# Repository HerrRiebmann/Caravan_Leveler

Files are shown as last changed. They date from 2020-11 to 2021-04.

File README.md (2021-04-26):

# Caravan Leveler
ESP32 digital water level bubble with an ADXL345 Accelerometer

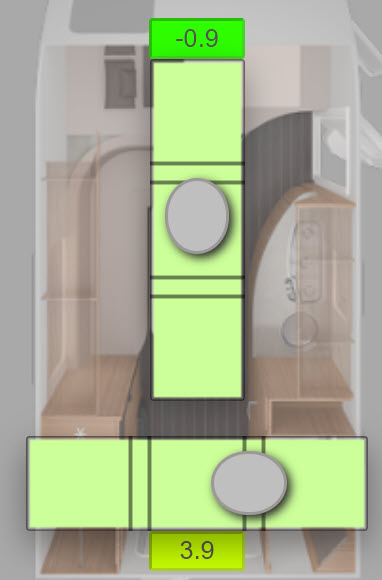
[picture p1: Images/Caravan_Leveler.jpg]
Caravan Leveler


An ESP WROOM32 will create a hotspot with a captive portal.
This captive portal will force the phone to open up a login-site (_which represents the water level_).

## Contents
* [Usage](#usage)
* [Video](#video)
* [3D Case](#3D-Case)
* [Things](#Things)
* [HardwareComponents](#HardwareComponents)
  * [Wiring](#Wiring)
  * [SPIFFS Upload](#SPIFFS-Upload)
  * [Libraries](#Libraries)
  * [OTA (Over the Air Update)](#OTA-Over-the-Air-Update)
  * [Power switch](#Power-Switch)
* [Compatibility](#Compatibility)
* [Disclaimer](#Disclaimer)

### Intention
The intention was, to attach this to my caravan (_Knaus Sport & Fun_) and provide it with 12V on-board voltage.
When arriving at a campingside, the phone will automatically connect to this as a known hotspot, open up the digital leveler and I can happily crank the supports.

In short: Lazy me doesn´t want to constantly walk to the inside and check the level &#129335;

## Usage

Captive Portal (_Android 10_):

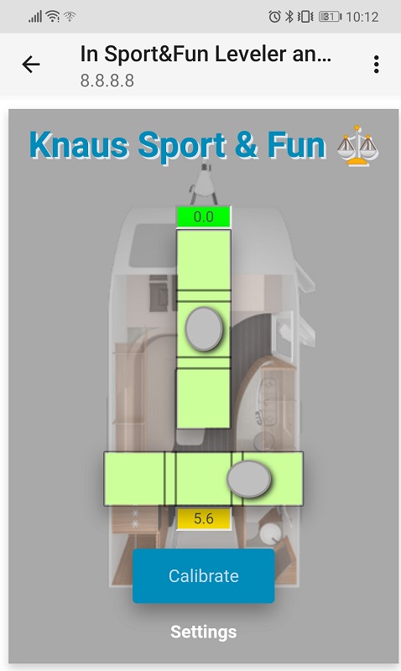
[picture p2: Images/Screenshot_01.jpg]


**Calibrate** sets the values to zero

Settings:

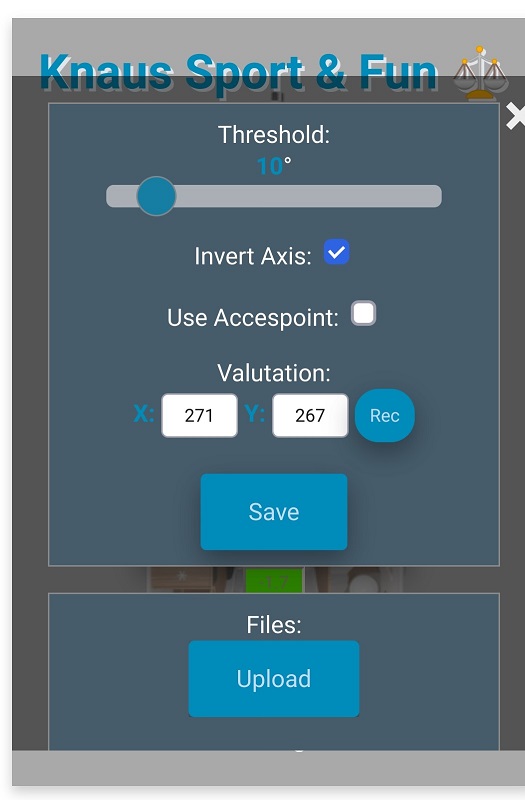
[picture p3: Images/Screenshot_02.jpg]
Settings


**Threshold** describes the water bubble maximum value, when it will reach the scales end

**Invert Axis** swaps X- and Y-Axis

**Use Accesspoint** or connect to an existing WiFi (_SSID and Pasword required in code_)

**Valutation** represents the values range from 0° to 90° (_or -90° to 0°_)

**Rec** starts recording the minimum and maximum values on both axis. Tip the board over to 90 degrees on every side. Afterwards, hit **End** to see those values.

**Save** will store all values above, to the ESP32

**Upload** loads a file to the SPIFFS. To overwrite existing files, the filename must be equal (see [/data](https://github.com/HerrRiebmann/Caravan_Leveler/tree/main/data))!

## Video
(http://www.youtube.com/watch?v=iUhjaghWvkY "Caravan Leveler")

## 3D Case
3D Printed case with wood filament:

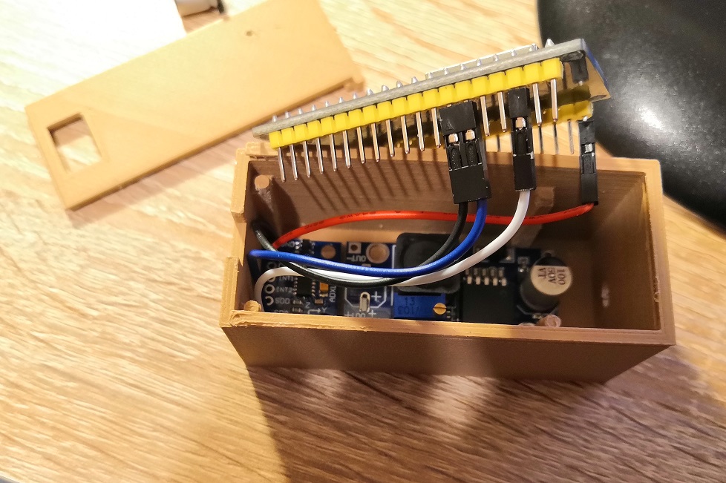
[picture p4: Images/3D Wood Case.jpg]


**Attention!** The wood filament comes thicker, so you might have to sand parts of the case. That´s not necesary using regular PLA.

Hotspot (_Android 4.4.3_):

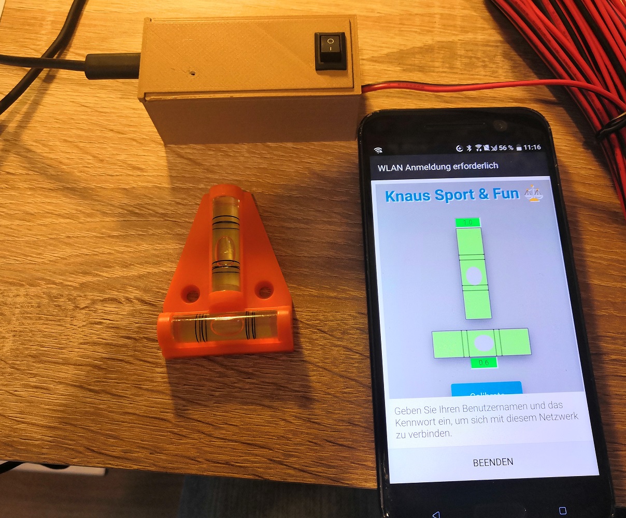
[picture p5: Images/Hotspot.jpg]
Hotspot


## Things
### HardwareComponents
* ESP WROOM32
* ADXL345 (_Accelerometer / Gyro_)
* LM2596 (_DC-DC converter_)
* Rocker switch (_15mm x 10mm_)
* 3D Printed Case

### Wiring
ESP 32 | ADXL345
------- | --------
G22 | SCL
G21 | SDA
3.3V | VCC
GND | GND

ESP 32 | LM2596
------- | --------
5V | OUT+
GND | OUT-

### SPIFFS Upload
To upload the HTML, JS and CSS files, I´ve used the [Arduino ESP32 filesystem uploader](https://github.com/me-no-dev/arduino-esp32fs-plugin)
You can find the latest release [here](https://github.com/me-no-dev/arduino-esp32fs-plugin/releases/) and a tutorial on [RandomNerdTutorials](https://randomnerdtutorials.com/install-esp32-filesystem-uploader-arduino-ide/)

### Libraries
* Adafruit Unified Sensor (1.0.3)
* Adafruit ADXL345 (1.2.2)

### OTA (Over the Air Update)
You should see the ESP32 in Arduino IDE under Tools -> Port -> Network-Interfaces (Sport&Fun Leveler at _IP-Adress_)
For more information see [RandomNerdTutorials](https://randomnerdtutorials.com/esp32-over-the-air-ota-programming/)

### Power Switch
The DC converter is connected to the 12V net. So it will only be powered, enabling the boardnet (_as you can see at the start of the video_).
To prevent the converter being powered all the time, standing on a campingside, I´ve added a illuminated momentary switch:
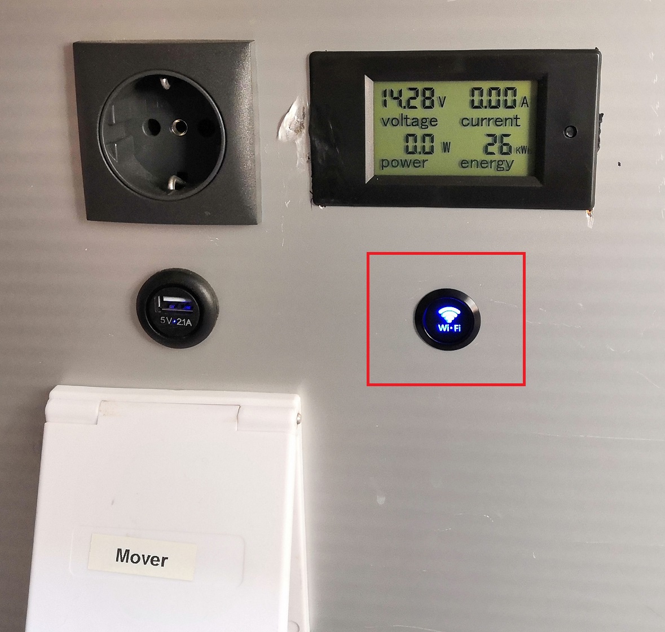
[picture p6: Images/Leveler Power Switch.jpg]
Power Switch

19mm momentary blue led switch. Color and various logos can be ordered on well known, chinese express online shop ;) 

Got a relais in between, which disconnects after about 15 minutes, after powering up.
Not easy to find the right one, which immediately closes the relais and opens it after a specific period of time.
Then remain like that, until the powersupply is cut off. A **JK 11** timing relais (V2.0.2021-1) worked great, using a jumper instead of a trigger button.
But not yet constantly installed...

## Compatibility
Tested on iOS and Android 4.4.3, 8 and 10.

(*And all estabished none-mobile Browsers, like Firefox, Edge or Chrome*)

### Disclamer
The ADXL345 is **not** a proper device to show exact degrees! It´s an accelerometer, which goal was to measure movements by gravitation.
So all results are just approximation.

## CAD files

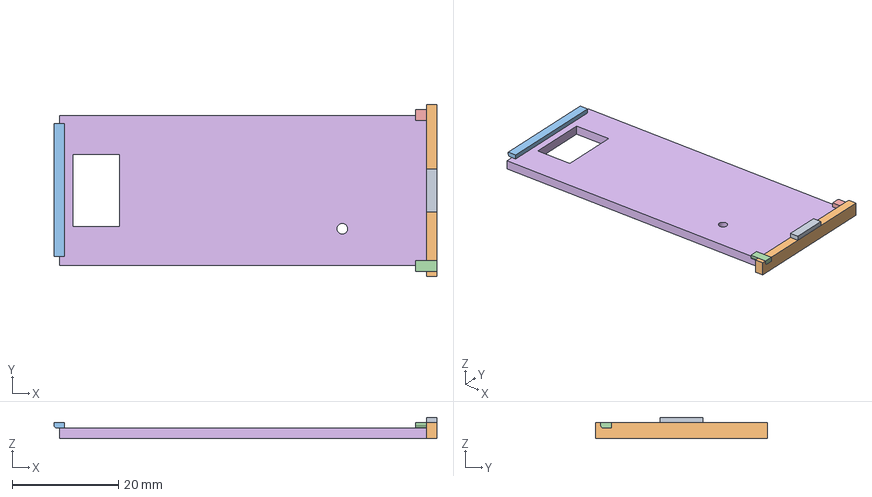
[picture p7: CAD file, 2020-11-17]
3D Case/Camping Leveler - Lid.FCStd
72.0 x 32.4 x 4.00 mm
USB Cut
BaseEnd

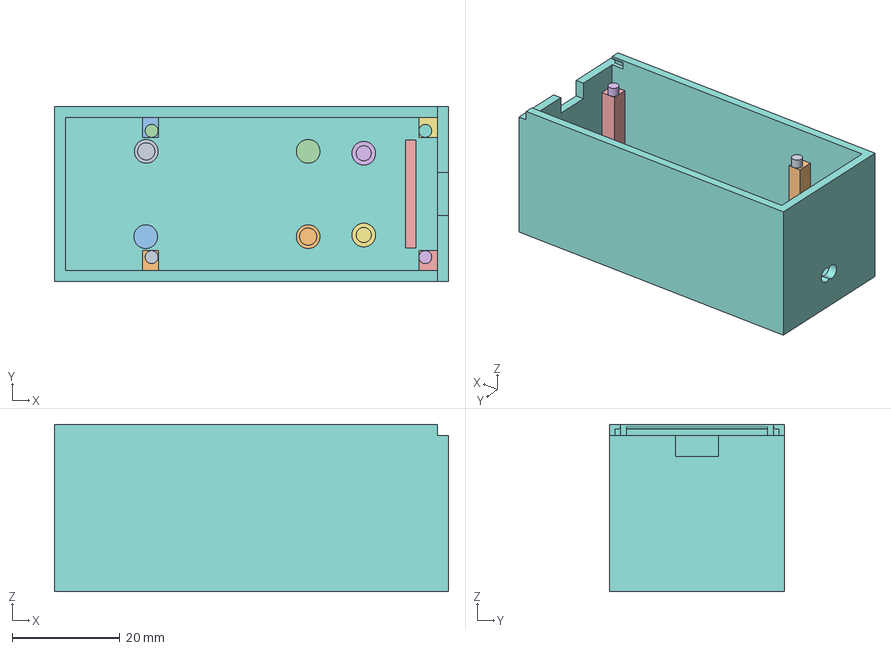
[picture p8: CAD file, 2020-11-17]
3D Case/Camping Leveler - Box.FCStd
73.0 x 32.4 x 31.0 mm
Pin1
Pin2
BaseZylinder002
BaseZylinder003
Stand1
Stand2
Stand3
Stand4
Würfel
Pin3
Pin4

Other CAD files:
3D Case/CampingLevelerBox.stl
3D Case/CampingLevelerLid.stl

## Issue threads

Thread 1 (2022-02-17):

Befestigung der Leiterplatten im Gehäuse

xsnoopy1958, 2022-02-17:
Hallo,
ich bin dabei das Projekt nachzubauen.
3D-Gehäuse ist auch schon gedruckt.
Wie befestigt man nun am besten die Leiterplatten in dem Gehäuse?

Danke für Hilfe und Rückmeldung

HerrRiebmann, 2022-02-17:
Hi,
freut mich, dass Du die digitale Wasserwaage nachbaust :)
Im Gehäuse sind unten kleine "Pinne", wo der Gyro eingeklipst werden kann (auf der Seite des USB-Ausschnittes.
Auf der anderen Seite kommt dann das Netzteil hin.
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
Zu guter Letzt sind noch 4 Stege nach oben rausgeführt, wo dann der ESP sitzen soll.

Sehe aber gerade, dass mein ESP wohl die Ausführung mit mehr Pins ist. Der ist nämlich länger als die anderen, die ich hier liegen habe:
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
Wenn Du mir die Ausmaße gibst, kann ich die sicherlich kurz umkonstruieren!

xsnoopy1958, 2022-02-17:
Hallo ,
danke für die schnelle Antwort.
ja, die Pins habe ich schon gefunden, mache mir nur etwas Sorgen, dass die Leiterplatten sich auf dauer lösen können.
Kann man eine zusätzliche Sicherung anbringen, damit sie wirklich dauerhaft fest sitzen?
Könnte evtl. ein kleiner Tropfen Heißklebstoff nützlich sein?
Gibt es eine Möglichkeit das Bild mit dem Knaus Wohnwagen auf ein anderes Wohnwagenmodell zu ändern?
Noch ne Frage: ist die Level-Anzeige genau genug?
Gruß
Bernd

xsnoopy1958, 2022-02-17:
Habe noch etwas vergessen,
der Deckel ist sehr locker im Gehäuse.
Wie kann ich den gut und fest fixieren?

HerrRiebmann, 2022-02-17:
Hi Bernd,
bei mir sitzt die Platine wirklich spack auf diesen Pins. Da bewegt sich nichts, auch während zahlreichen Fahrten ist alles noch an Ort und Stelle.
Ein Tröpfchen Heißkleber schadet sicherlich nicht. Sei aber bitte vorsichtig, denn zu meiner Überraschung leitet der Kleber.
Hat in einem Projekt mit Touch-Bedienung zu zahlreichen grauen Haaren geführt.

Der Deckel ist leider recht stümperhaft mit meinen CAD-Fähigkeiten entstanden...
Würde ich heutzutage sicherlich anders lösen. Vielleicht schiebe ich mal ein Update nach, welches auch verschiedene ESP32-Formate unterstützt.

Es gibt unter den Einstellungen einen "Upload"-Button. Da kannst Du das Bild einfach vom Handy oder Computer direkt auf dem ESP32-Speicher ersetzen. Es muss nur "caravan.png" heißen.
Oder Du ersetzt es schon beim ersten Einrichten vom ESP32. Dort liegt das Bild im Arduino Sketch-Verzeichnis unter "\data\caravan.png".

Die Genauigkeit reicht mir vollkommen aus. Besser wird es mit einer analogen Wasserwaage auch nicht.
Habe allerdings den "Threshold" also den Schwellwert von 10° auf 5° verringert. Dann ist´s perfekt!

xsnoopy1958, 2022-02-17:
Hi Herr Riebmann,
vielen Dank für die schnelle Antwort.
Noch eine andere Frage: auf einem der Bilder ist eine Spannungs-/Strom-/Energieanzeige zu sehen.
Hast du dafür auch eine Bauanleitung oder wo kann man so etwas kaufen?

Gruß
Bernd

HerrRiebmann, 2022-02-18:
Hallo Bernd,

meinst Du die [Anzeige ](https://github.com/HerrRiebmann/Caravan_Leveler/blob/main/Images/Leveler%20Power%20Switch.jpg) von meiner Photovoltaik-Anlage?
Ansonsten hat [hier](https://github.com/HerrRiebmann/Caravan_Leveler/blob/main/Images/Leveler%20Power%20Switch.jpg) jemand den Aufbau um einen Spannungsteiler erweitert und lässt sich die Spannung auf dem Handy mit anzeigen.
Viel Erfolg bei der Umsetzung,
Thomas

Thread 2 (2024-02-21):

Fehler beim Kompilieren

lety2000, 2024-02-21:
Hallo,

ich bin gerade dabei, den Leveler nachzubauen. Vielen Dank für die Dokumentation des Projektes! Beim Kompilieren bei treten einige Fehler auf:

 C:\Users\***\Documents\Arduino\Caravan_Leveler-main\Caravan_Leveler\Caravan_Leveler.ino: In function 'void setup()':

Caravan_Leveler:51:3: error: 'SerialBegin' was not declared in this scope

C:\Users\***\Documents\Arduino\Caravan_Leveler-main\Caravan_Leveler\Caravan_Leveler.ino:51:3: note: suggested alternative: 'Serial2'

Caravan_Leveler:52:3: error: 'Adxl345Begin' was not declared in this scope

Caravan_Leveler:53:3: error: 'EepromBegin' was not declared in this scope

C:\Users\***\Documents\Arduino\Caravan_Leveler-main\Caravan_Leveler\Caravan_Leveler.ino:53:3: note: suggested alternative: 'uartBegin'

Caravan_Leveler:55:3: error: 'LoadData' was not declared in this scope

Caravan_Leveler:57:3: error: 'SpiffsBegin' was not declared in this scope

C:\Users\***\Documents\Arduino\Caravan_Leveler-main\Caravan_Leveler\Caravan_Leveler.ino:57:3: note: suggested alternative: 'timerBegin'

Caravan_Leveler:58:3: error: 'WiFiBegin' was not declared in this scope

C:\Users\***\Documents\Arduino\Caravan_Leveler-main\Caravan_Leveler\Caravan_Leveler.ino:58:3: note: suggested alternative: 'timerBegin'

Caravan_Leveler:59:3: error: 'setupOTA' was not declared in this scope

C:\Users\***\Documents\Arduino\Caravan_Leveler-main\Caravan_Leveler\Caravan_Leveler.ino:59:3: note: suggested alternative: 'setup'

C:\Users\***\Documents\Arduino\Caravan_Leveler-main\Caravan_Leveler\Caravan_Leveler.ino: In function 'void loop()':

Caravan_Leveler:75:7: error: 'getLevel' was not declared in this scope

C:\Users\***\Documents\Arduino\Caravan_Leveler-main\Caravan_Leveler\Caravan_Leveler.ino:75:7: note: suggested alternative: 'geteuid'

Mehrere Bibliotheken wurden für "WiFi.h" gefunden

 Benutzt: C:\Users\***\AppData\Local\Arduino15\packages\esp32\hardware\esp32\2.0.11\libraries\WiFi

 Nicht benutzt: C:\Program Files (x86)\Arduino\libraries\WiFi

exit status 1

'SerialBegin' was not declared in this scope

Leider kann ich im Netz nichts Konkretes finden, was mir weiterhelfen würde.
Ich habe den Ordner "Data" Sketch Data Upload bereits auf den ESP hochgeladen.
Können Sie mir sagen, woran es hakt?
Vielen Dank!

HerrRiebmann, 2024-02-21:
Hi,

das sieht mir sehr danach aus, als sind nicht alle Dateien aus dem Ordner kopiert worden.
Die `Caravan_Leveler.ino` ist nur die "_Start_"-Datei. Alle weiteren *.ino-Dateien müssen ebenfalls in dem Verzeichnis liegen.
Und der Ordner "/data" ist notwendig, damit im nächsten Schritt die Dateien für die Webseite auf den ESP übertragen werden können.
Das habe ich dann her beschrieben:
https://github.com/HerrRiebmann/Caravan_Leveler?tab=readme-ov-file#SPIFFS-Upload

lety2000, 2024-02-21:
Das Problem lag an mir...die zusätzlichen .ino Dateien lagen tatsächlich im falschen Ordner. Jetzt hat es geklappt, ich kann eine Verbindung zum ESP herstellen.
Vielen Dank für die schnelle Antwort!

Closed 2024-02-21.

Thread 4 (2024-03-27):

error message and libraies version

marcsauter75, 2024-03-27:
Hi,

I did an upload to my ESP32 and got following error message

****************************************************************************

 #include <Adafruit_I2CDevice.h>
          ^~~~~~~~~~~~~~~~~~~~~~
compilation terminated.
*** [.pio/build/denky32/lib170/Adafruit ADXL345/Adafruit_ADXL345_U.cpp.o] Error 1
========================================================= [FAILED] Took 1.19 seconds =========================================================

further the version of the libs named in in the docu are outdated and not available anymore.
could that be a problem ?

HerrRiebmann, 2024-03-27:
Hi Marc,
are you using the ESP32 Version greater than 2.0.0?

Then I need to update the code and it´s dependencies.
Currently I´m using an ESP32Cam which did not work properly with more than 1.6.0, so I´m still on it.

marcsauter75, 2024-03-27:
It´s a good question ;)
I have a integrated ESP32-WROOM-32 Battery board.
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

marcsauter75, 2024-03-27:
Maybe there are some other libraries missed ?  I am not 100% sure ?

HerrRiebmann, 2024-03-27:
I meant the board Firmware:
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
Mine is outdated, but works fine with the libraries.

So I suppose that you are using a newer Version which might is not compatible.
Maybe I can check that tomorrow.

marcsauter75, 2024-03-27:
In Arduino I got no board info.
I work also with VSCode for uploading.
It is not working with the .jar file for me...
Maybe there will be a bin file for me wich is easier to install.
But thanks for your support.

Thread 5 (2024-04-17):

Base for the box

FrufoFPV, 2024-04-17:
Thanks for the project. I've build this already two years ago and it worked great so far.

I've created a base for the case  that i like to share. It is a press fit for the original case and  can be screwed down to fix the box.
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

[Levelerboden v3.stl.zip](https://github.com/HerrRiebmann/Caravan_Leveler/files/15010884/Levelerboden.v3.stl.zip)

I've also modified the UI to match my camper and to match the color scheme of the Victron app.

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

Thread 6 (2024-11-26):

Webserver File Not Found

RostigerRitter, 2024-11-26:
Hallo Herr Riebmann,

ich habe das Problem, dass nach dem Verbinden mit dem Controller das Captive Portal auf geht,
aber die Fehlermeldung File Not Found kommt. (Siehe Bild)
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
Die Daten wurden per SPIFFS hochgeladen.
Haben Sie eine Idee um das Problem zu lösen?

Vielen Dank,

Daniel

HerrRiebmann, 2024-11-27:
Hallo Daniel,
das ist AdHoc natürlich imme schwierig zu sagen woran es genau liegt.
Der Aufruf zur URL " / " sollte automatisch auf die index.html weiterleiten.
Was passiert, wenn man die URL manuell angibt?
`http://8.8.8.8/index.html`
Und was gibt der Serielle Monitor aus? Auf **115200** Baud sollte da etwas über die angefragte Datei und vielleicht auch schon den Grund weshalb sie nicht gefunden wird, ausgegeben werden.

Viel Erfolg!
Thomas

HerrRiebmann, 2024-11-28:
Hi Daniel,
der Screenshot hilft!
Der Code verwendet SPIFFS, was zugegeben veraltet ist. Aber schön kompatibel mit dem ESP8266.
Du verwendest das modernere und auch empfohlene LittleFS Dateisystem.

Entsprechend müsstest Du anstelle von
```
//Filesystem
#include "SPIFFS.h"

void SpiffsBegin() {
  if (!SPIFFS.begin(true))
    Serial.println("An Error has occurred while mounting SPIFFS");
}
```

Eher sowas verwenden:
```
#include "FS.h"
#include <LittleFS.h>

if(!LittleFS.begin(FORMAT_LITTLEFS_IF_FAILED, "/lfs2", 5, "part2")){
    Serial.println("part2 Mount Failed");
    return;
    }
```
Mit Suchen & Ersetzen könnte das eigentlich klappen, da beides auf FS.h aufbaut und die Funktionen darin identisch benannt sind.

Oder eben den Dateiupload auf ein anderes Tool umstellen.

RostigerRitter, 2024-12-07:
Hallo Thomas,
vielen Dank für deine Antwort.
Der erste Versuch den Code zu ändern auf LittleFS ist leider fehlgeschlagen.
Mit der alten IDE 1.8 und SPIFFS Plugin hat es ohne Problme funktioniert.
Nochmal vielen Daank für deine Unterstützung und mach weiter so. 👍

Moustik1978, 2025-07-05:
Guten morgen,

Wollte dies auch mal austesten.

Leider komme ich auch auf die Seite File not found.

Hab also die arduino 1.8.0 IDE installiert und probiert.

Da kommt genau das gleiche raus.

Closed 2025-09-24.

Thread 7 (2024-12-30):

how to calibrate

Heiner1967, 2024-12-30:
Hi,

its a cool tool which you build, however i do not get how you doe the calibration.

IF you arrieve somewhere you are not leveled, The sensor as of beginning of measure, just collect chnage but no absolut level, correct?

Means you can only show how the level change since last calibration which is the start ofmeasure when you arrive somewhere.

Am I wrong?

Thanks for letting me know

HerrRiebmann, 2025-01-04:
Hello Heiner,
the initial calibration "Set valuation" (_turn the Gyro in any direction to get the max values_) is only needed once.
And to be done on the bench, rather than in the caravan ;)
Leveling it then to zero  by "Calibrate" can also be done directly after programming the ESP, by laying it down on a flat surface.
But this would require it to be mounted flat in the caravan.
Since I do not know if the 3d Printed case is leveled or the place where it will be mounted, you can also attach it to the caravan (_with double sided adhesive_), then use a classic waterbubble to align every axis straight and then calibrate the ESP.

That´s it. From then on you will never need to do this again and the waterbubble can be left at home.
The values were stored, even if it looses power. So changing your location, powerup the ESP and connect to it via a mobile phone. No calibration needed.

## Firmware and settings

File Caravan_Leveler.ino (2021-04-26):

//Gyro ADXL345
#include <Wire.h>
#include <Adafruit_ADXL345_U.h>
/* Assign a unique ID to this sensor at the same time */
Adafruit_ADXL345_Unified accel = Adafruit_ADXL345_Unified(12345);

//Filesystem
#include "SPIFFS.h"
#include "EEPROM.h"
#define EEPROM_LEVEL_X 0
#define EEPROM_LEVEL_Y 2
#define EEPROM_VALUATION_X 4
#define EEPROM_VALUATION_Y 6
#define EEPROM_LEVEL_THRESHOLD 8
#define EEPROM_LEVEL_INVERTATION 9
#define EEPROM_LEVEL_ACCESSPOINT 10

//Webserver
#include <WiFi.h>
#include <WebServer.h>
const char* ssid = "FindMichDoch2";
const char* password = "5AF714A8B";

WebServer webServer(80);

#include <DNSServer.h>
const byte DNS_PORT = 53;
DNSServer dnsServer;

//Over the Air Update
#include <ArduinoOTA.h>

const char deviceName[] = "Sport&Fun Leveler";

bool accelInitialized = false;
int levelX = 0;
int levelY = 0;
int calibrationX = -150;
int calibrationY = -25;
int valuationX = 271;
int valuationY = 267;
bool valuationActive = false;
uint8_t levelThreshold = 5;
bool invertAxis = false;
bool useAcessPointMode = false;

long lastMillis = 0;
long lastMillisClientAvailable = 0;

void setup() {
  SerialBegin();
  Adxl345Begin();
  EepromBegin();  

  LoadData();

  SpiffsBegin();
  WiFiBegin();
  setupOTA();
}

void loop() {
  //WebServer
  webServer.handleClient();

  //DNS
  dnsServer.processNextRequest();

  //OTA
  ArduinoOTA.handle();
  
  if(millis() - lastMillis > 200){
    //Only update when someone is listening:
    if(millis() - lastMillisClientAvailable < 1000)
      getLevel();
    lastMillis = millis();
  }
}

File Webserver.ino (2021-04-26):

void WiFiBegin() {
  //Manually change between WiFi and Accesspoint. AP will be used as a fallback, after 5 seconds
  if (useAcessPointMode)
    CreateAccessPoint();
  else
    ConnectToAccessPoint();
  
  webServer.on("/level", handle_level);
  webServer.on("/setup", handle_setup); 
  webServer.on("/calibrate", handle_calibrate);
  webServer.on("/valuate", handle_valuation);
  webServer.on("/reset", handle_reset);
  webServer.on("/upload",  HTTP_POST,[](){ webServer.send(200);}, handle_fileupload);

  //Allways redirect to captive portal. Request comes with IP (8.8.8.8) or URL (connectivitycheck.XXX / captive.apple / etc.)  
  webServer.on("/generate_204", redirect);    //Android captive portal.
  webServer.on("/fwlink", redirect);   //Microsoft captive portal.
  
  webServer.on("/connecttest.txt", redirect); //www.msftconnecttest.com
  webServer.on("/hotspot-detect.html", redirect); //captive.apple.com
  
  webServer.on("/success.txt", handle_success); //detectportal.firefox.com/sucess.txt
  webServer.onNotFound(handleFileRead);

  const char* Headers[] = {"If-None-Match"};
  webServer.collectHeaders(Headers, sizeof(Headers) / sizeof(Headers[0]));

  webServer.begin();
  Serial.println(F("HTTP webServer started"));
  delay(100);
}

void ConnectToAccessPoint() {
  WiFi.begin(ssid, password);

  long start = millis();
  while (WiFi.status() != WL_CONNECTED) {
    delay(1000);
    Serial.print(".");
    if (millis() - start > 5000) {
      Serial.println("Wifi not found!");
      CreateAccessPoint();
      return;
    }
  }
  Serial.println();
  Serial.println(F("WiFi connected successfully"));
  Serial.print(F("Got IP: "));
  Serial.println(WiFi.localIP());  //Show ESP32 IP on serial
}

void CreateAccessPoint() {
  WiFi.disconnect();
  IPAddress local_ip(8, 8, 8, 8);
  IPAddress gateway(8, 8, 8, 8);
  IPAddress subnet(255, 255, 255, 0);

  WiFi.mode(WIFI_AP);
  WiFi.softAP(deviceName);
  delay(500);
  WiFi.softAPConfig(local_ip, gateway, subnet);
  delay(500);
  Serial.print(F("AP IP address: "));
  Serial.println(WiFi.softAPIP());

  /* Setup the DNS webServer redirecting all the domains to the apIP */
  dnsServer.setErrorReplyCode(DNSReplyCode::NoError);
  dnsServer.start(DNS_PORT, "*", local_ip);
}

void handle_root() {
  // /
  // /index.html  
  Serial.println(F("Handle Root"));

  PrintIncomingRequest();
  
  String path = "/index.html";
  if (!SPIFFS.exists(path))
    return;

  File f = SPIFFS.open(path);
  webServer.streamFile(f, "text/html");
  f.close();
}

void handle_level() {
  // /level
  if (!accelInitialized) {
    webServer.send(400, "text/plain", "Gyro not initialized!");
    return;    
  }

  String txt = String(invertAxis ? levelY : levelX);
  txt.concat("|");
  txt.concat(String(invertAxis ? levelX * -1 : levelY));
  txt.concat("|");
  txt.concat(String(levelThreshold));
  String customText = GetCustomText();  
  if(customText.length() > 0){    
    txt.concat("|");
    txt.concat(customText);
  }
  webServer.send(200, "text/plain", txt);

  lastMillisClientAvailable = millis();
}

void handle_setup() {
  // /setup
  Serial.println(F("Handle Setup"));

  //With arguments:
  // /setup?x=123&y=321&inv=0&ap=1
  ProcessSetupArguments();

  String txt = String(accelInitialized);
  txt.concat("|");
  txt.concat(String(valuationX));
  txt.concat("|");
  txt.concat(String(valuationY));
  txt.concat("|");
  txt.concat(String(invertAxis));
  txt.concat("|");
  txt.concat(String(useAcessPointMode));
  webServer.send(200, "text/plain", txt);
}

void handle_calibrate() {
  Serial.println(F("Handle Calibration"));
  CalibrateLevel();
  String result = "Calibration OK (";
  result.concat(calibrationX);
  result.concat("/");
  result.concat(calibrationY);
  result.concat(")");
  webServer.send(200, "text/plaint", result);
}

void handle_valuation() {
  Serial.println(F("Handle Valuation"));  
  String result = "Calibration ";
  if(valuationActive)
    result.concat("stopped");
  else {
    minValuationX = 0;
    minValuationY = 0;
    maxValuationX = 0;
    maxValuationY = 0;
    result.concat("started");
  }
  valuationActive = !valuationActive; 
  webServer.send(200, "text/plaint", result);
}

void handle_reset(){
  LoadData();
  webServer.send(200, "text/plaint", "OK");
}

void handleNotFound() {
  Serial.println(F("HandleNotFound"));

  PrintIncomingRequest();

  if (captivePortal())
    return;
  String message = F("File Not Found\n\n");
  message += F("URI: ");
  message += webServer.uri();
  message += F("\nMethod: ");
  message += (webServer.method() == HTTP_GET) ? "GET" : "POST";
  message += F("\nArguments: ");
  message += webServer.args();
  message += F("\n");

  for (uint8_t i = 0; i < webServer.args(); i++) {
    message += String(F(" ")) + webServer.argName(i) + F(": ") + webServer.arg(i) + F("\n");
  }
  webServer.sendHeader("Cache-Control", "no-cache, no-store, must-revalidate");
  webServer.sendHeader("Pragma", "no-cache");
  webServer.sendHeader("Expires", "-1");
  webServer.send(404, "text/plain", message);
}

void handle_success(){
  Serial.println(F("Handle success.txt"));
  webServer.send(200, "text/plain", "success");
}

boolean captivePortal() {
  Serial.print(F("Captive Check: "));
  Serial.println(webServer.hostHeader());
  if (!isIp(webServer.hostHeader())) {
    Serial.println("-Request redirected to captive portal");
    redirect();
    return true;
  }
  return false;
}

void redirect(){
  webServer.sendHeader("Location", String("http://") + toStringIp(webServer.client().localIP()), true);
  webServer.send(302, "text/plain", "");   // Empty content inhibits Content-length header so we have to close the socket ourselves.
  webServer.client().stop(); // Stop is needed because we sent no content length
}

void PrintIncomingRequest(){  
  Serial.println(webServer.hostHeader());
  Serial.print("  ");
  Serial.println(webServer.uri());
  
  for (uint8_t i = 0; i < webServer.args(); i++)
    Serial.println(String(F(" ")) + webServer.argName(i) + F(": ") + webServer.arg(i) + F("\n"));
  
  for (int i = 0; i < webServer.headers(); i++)
    Serial.println(String(F("\t")) + webServer.headerName(i) + F(": ") + webServer.header(i));  
}

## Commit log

2020-11-17 Initial Upload
    First commit
    [Camping Leveler - Box.FCStd, Camping Leveler - Lid.FCStd, CampingLevelerBox.stl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]
2020-11-20 Deeppass-Filter Optimized WebRequests
    Added a deep-pass filter to smooth the values
    optimized the transfer of setup values
    introduced a switch to change between WiFi and AccessPoint
2021-01-27 DocType and Firefox success check
    Added success.txt-handle for Firefox
    Added "DOCTYPE html" and fixed positions with "px"
    [Webserver.ino]
2021-01-28 Enhanced Captive Portal
    Tested more devices, browser and operation systems.
2021-01-29 Threshold-Bug
    Threshold Setup Storing
    Valuation optimization
    [Helper.ino, Valuation.ino, WebFile.ino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]
2021-01-30 Invert X-Axis
    When swapping X and Y axis. X must be negotiated.
2021-04-26 Added power switch
2021-04-26 Added label for custom text
    Custom Text can now be added in the function GetCustomText() to f.e. return voltages or something
